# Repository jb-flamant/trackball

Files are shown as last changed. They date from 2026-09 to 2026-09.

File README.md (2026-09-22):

# Trackball 34 mm — PMW3610 / RP2040-Zero

Coque de trackball DIY paramétrique en OpenSCAD, dessinée pour une bille de
Ø34 mm, un capteur optique **PMW3610** et un microcontrôleur **RP2040-Zero**.

Le modèle est dérivé de [**Trackball 1.5** de jfedor (Printables #131450)](https://www.printables.com/model/131450-trackball-15),
conçu à l'origine pour une boule de billard Ø38 mm. Les cotes du support de
bille, de l'embase et du passage de câble ont été relevées sur les surfaces
analytiques du fichier source `Trackball15.step` (lecture cadquery/OCP, valeurs
exactes), puis transposées à la bille Ø34.

## Caractéristiques

- **Bille Ø34 mm** portée par 3 billes de roulement Ø2,5 (tripode à 60° du
  nadir, azimuts 30/150/270°), reprises telles quelles de l'original.
- **Retenue clipsable** (ajout par rapport à l'original) : trois languettes
  souples terminées par une lèvre arrondie empêchent la bille de sortir par le
  haut. Ouverture Ø33,46, clipsage/déclipsage par interférence, à la manière de
  la bague d'une Kensington Orbit.
- **Embase carrée** 52 × 55,75 mm, angles R8, montage par 4 vis M3 fraisées par
  dessous, taraudées dans la coque haute.
- **Passage de câble** en U dans la paroi avant, refermé par la coque haute
  (repris de l'original).
- Logements dédiés pour le breakout **PMW3610** (en long, optique centrée sous
  la bille) et le **RP2040-Zero** (en travers, derrière).

## Fichiers

| Fichier | Description |
| --- | --- |
| `trackball.scad` | Modèle paramétrique (OpenSCAD 2021.01). |
| `index.html` | Page de documentation (cotes, coupes, vues, reste à faire). |
| `*.png` | Rendus référencés par la page HTML. |

## Utilisation

Ouvrir `trackball.scad` dans [OpenSCAD](https://openscad.org/) (≥ 2021.01). La
variable `RENDER` sélectionne la pièce ou la vue à générer :

| Valeur | Rendu |
| --- | --- |
| `assembly` | Assemblage complet (défaut). |
| `top` | Coque haute (support de bille + retenue). |
| `bottom` | Bac électronique. |
| `section_h` | Coupe horizontale au plan des billes de roulement. |
| `section_v` | Coupe verticale (X = 0). |

Les principaux paramètres (diamètre de bille, jeux, interférence des lèvres,
dimensions des cartes, vis) sont regroupés en tête de fichier et documentés
inline. Exporter chaque pièce en STL depuis OpenSCAD pour l'impression.

Matière conseillée : **PETG** (le PLA est à la limite pour la flexion des
languettes de retenue).

## Reste à faire

Voir la section « Reste à faire avant impression définitive » de `index.html` :
support de lentille LM18-LSI/PMW3610 non modélisé, hypothèses sur la hauteur du
RP2040-Zero et le passage USB-C, coupon d'essai plaque + 3 poteaux recommandé
avant l'impression complète.

## Références

- [Trackball 1.5 — jfedor (Printables #131450)](https://www.printables.com/model/131450-trackball-15) — modèle de base.
- [siderakb/pmw3610-pcb](https://github.com/siderakb/pmw3610-pcb) — breakout PMW3610.
- [OpenSCAD](https://openscad.org/) — logiciel de CAO paramétrique.

## Crédits & licence

Travail dérivé de Trackball 1.5 (jfedor). Vérifier les conditions de licence du
modèle d'origine sur sa page Printables avant toute redistribution.

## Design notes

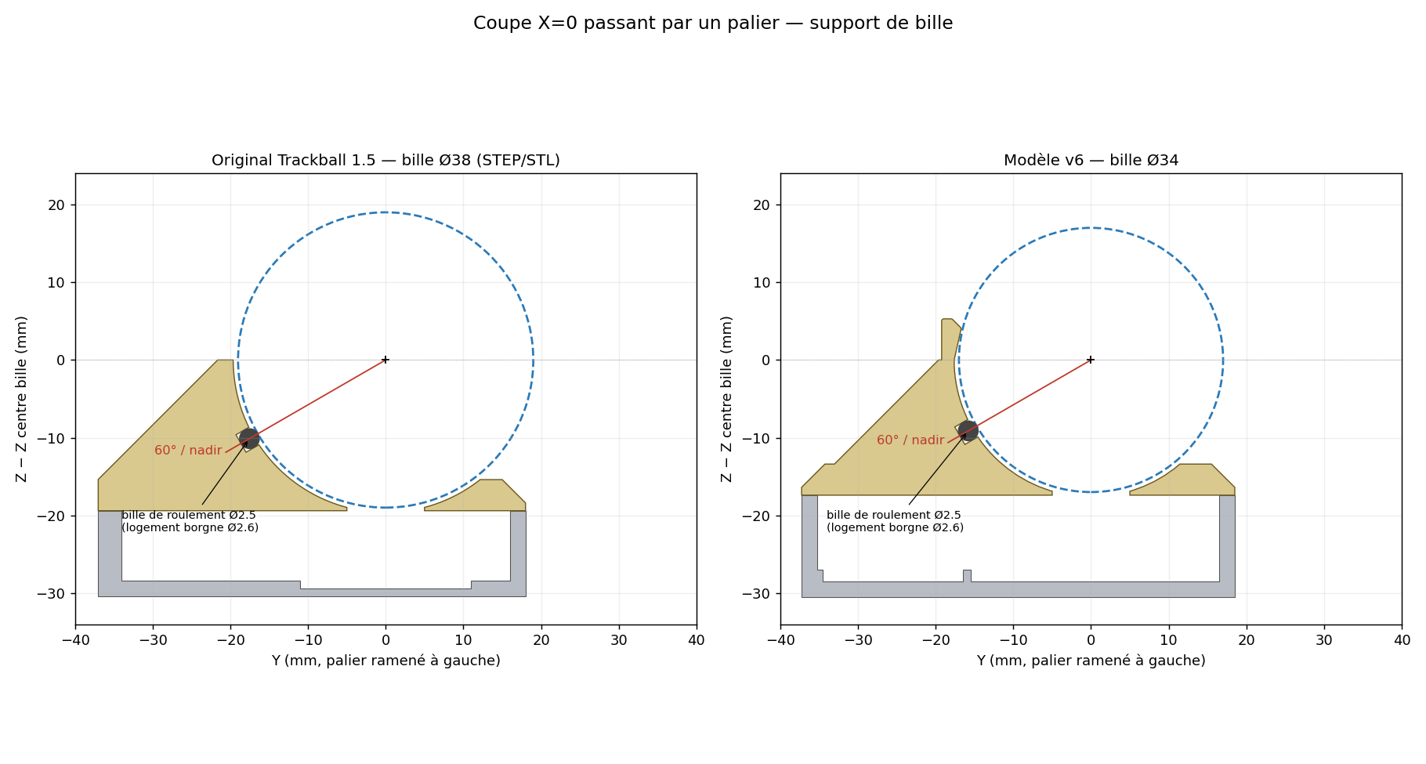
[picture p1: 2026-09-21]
comparaison_support_bille.png

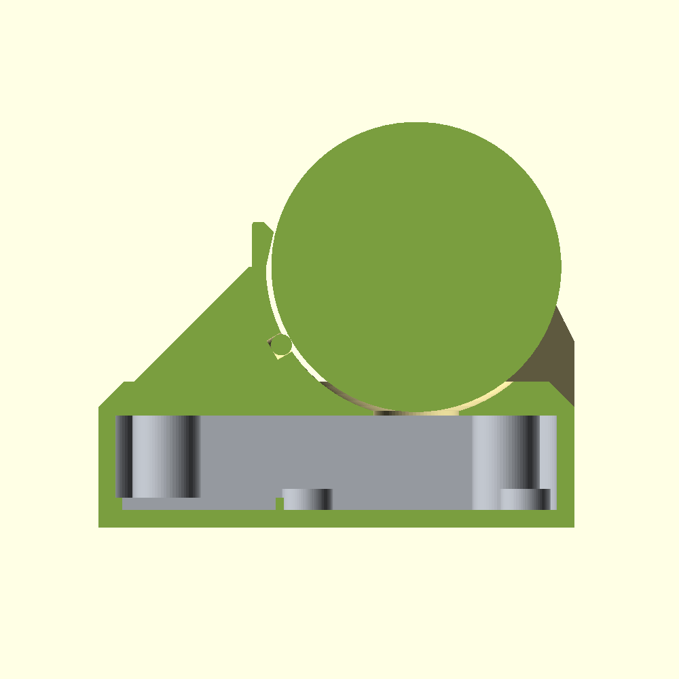
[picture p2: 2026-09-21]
section_verticale.png

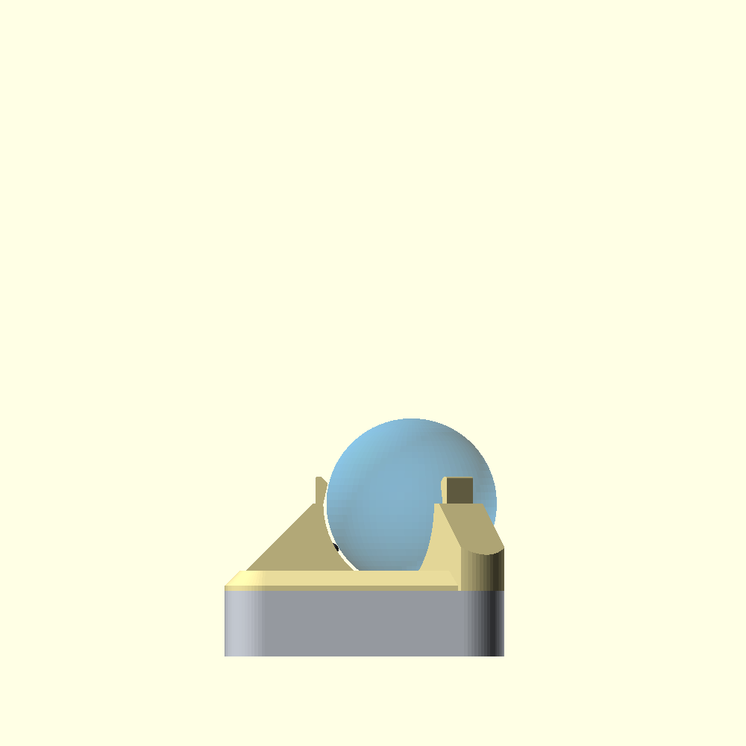
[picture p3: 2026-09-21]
view_droite.png

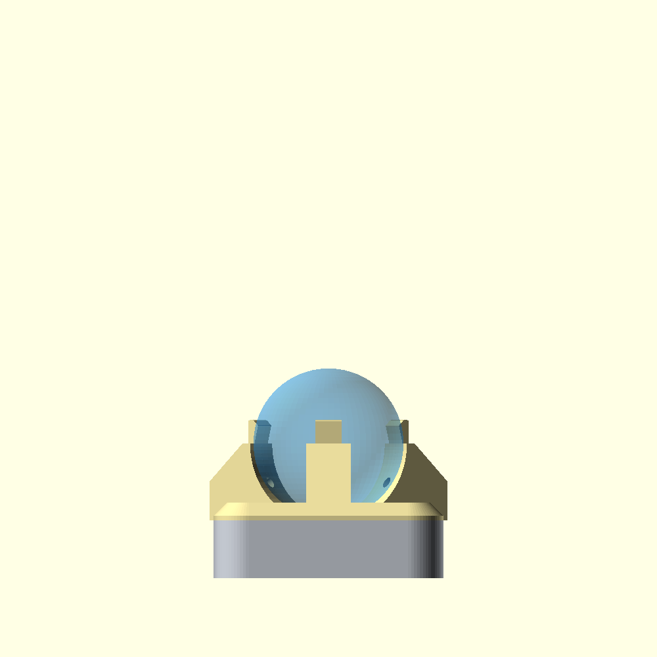
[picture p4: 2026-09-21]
view_dos.png

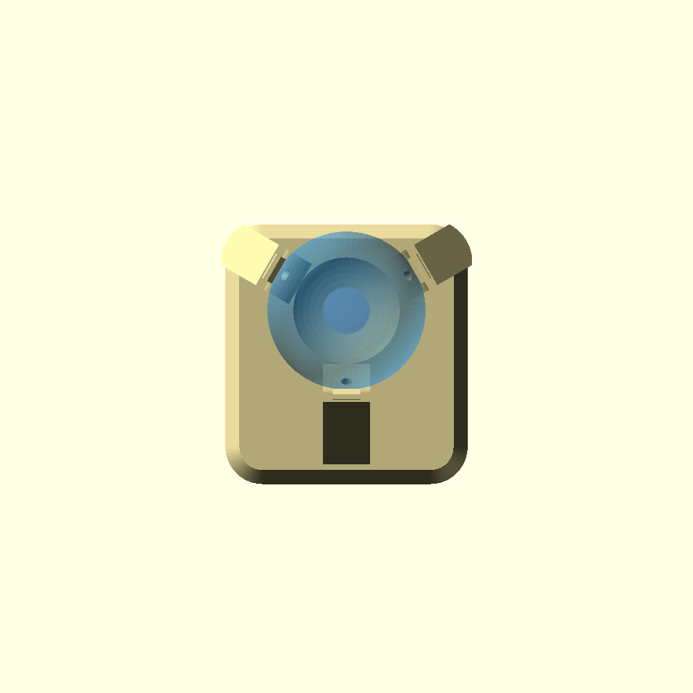
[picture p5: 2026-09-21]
view_haut.png

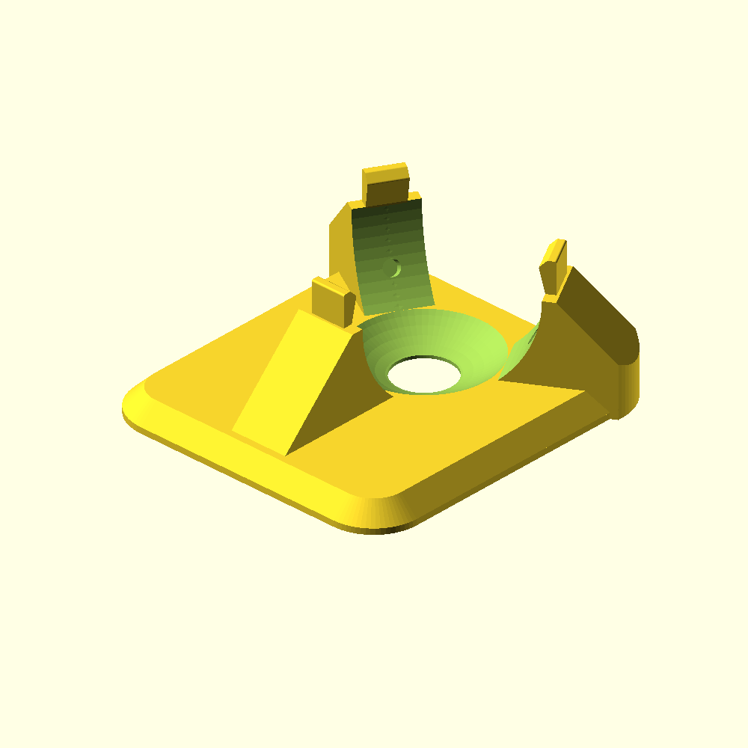
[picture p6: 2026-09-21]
iso_top_only.png

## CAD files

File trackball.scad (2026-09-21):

// =============================================================================
// Trackball DIY paramétrique — bille 34mm / PMW3610 / RP2040-Zero      (v7)
// =============================================================================
// Dérivé de "Trackball 1.5" (jfedor, Printables #131450), dessiné pour une boule de
// billard 38mm. Cotes lues sur les surfaces analytiques de Trackball15.step
// (cadquery/OCP), voir doc projet claude/mesures-step-trackball15.md.
//
// SUPPORT DE BILLE (v4, repris tel quel de l'original, transposé à 34mm) :
//   calotte R+0.625, ouverture Ø10, plaque 4mm, plan de joint 0.4mm sous le pôle sud,
//   3 billes de roulement Ø2.5 dans logements borgnes Ø2.6 à 60° du nadir, azimuts
//   30/150/270, murs-poteaux 10mm montant jusqu'à l'équateur.
// EMBASE CARRÉE (v5, reprise de l'original) :
//   corps rectangulaire largeur 52 (x ±26), angles R8, parois et fond 2mm, bord de
//   plaque vertical 1mm puis chanfrein 45° sur 3mm ; les poteaux dépassent le corps de
//   1mm (angles avant R9, nervure arrière) ; 4 vis M3 aux centres d'angle, montées par
//   dessous (fraisage dans le fond), taraudées dans la coque haute (avant trou pilote
//   Ø2.8 dans le poteau, arrière dans la plaque), comme sur l'original.
//   Profondeur : original y -36 → +18 autour de l'axe bille ; ici ajustée pour loger
//   le PMW3610 (en long, centré sous la bille) et le RP2040-Zero (en travers, derrière).
// RETENUE CLIPSABLE (v6, ajout, pas sur l'original) :
//   chaque poteau est prolongé au-dessus de l'équateur par une languette souple (6mm de
//   large, 1.6mm d'épaisseur) portant une lèvre arrondie tournée vers l'intérieur.
//   Ouverture entre les lèvres < Ø bille de 2×lip_interf : la bille se clipse en force
//   (rampe d'entrée à 45°) et se retire en tirant (face inférieure en pente), comme la
//   bague de la Kensington Orbit. Au repos, jeu lèvre/bille lip_clear ; la bille peut
//   se soulever d'environ 1mm avant de buter. Effort estimé ≈20N au total (PETG).
// PASSAGE DE CÂBLE (v7, repris de l'original) : encoche en U dans la paroi avant du bac
//   (côté bille), centrée x = -12, largeur 5, fond R2.5 à 5.5mm sous le plan de joint ;
//   la coque haute referme l'encoche.
// Provenance de chaque cote : STEP (mesuré sur l'original), DATASHEET, CHOIX.
// =============================================================================

/* [Bille] */
ball_d          = 34;      // spec projet (38 à l'origine)
ball_r          = ball_d/2;

/* [Support de bille] — STEP Trackball 1.5, valeurs indépendantes du diamètre */
cup_clearance   = 0.625;   // STEP : jeu radial calotte/poteaux ↔ bille
brg_ball_d      = 2.5;     // STEP : billes de roulement Ø2.5 (céramique/acier)
brg_hole_d      = 2.6;     // STEP : logement Ø2.6
brg_polar       = 60;      // STEP : angle depuis le nadir (60.0° exact)
brg_az          = [30, 150, 270]; // STEP : 30/150 vers les angles avant, 270 vers l'arrière
post_w          = 10;      // STEP : largeur des murs-poteaux
post_top_flat   = 2;       // STEP : épaisseur radiale du sommet plat
post_overhang   = 1;       // STEP : dépassement des poteaux hors du corps (R9 vs R8)
plate_t         = 4;       // STEP : épaisseur plaque haute (Z 7→11)
plate_edge_v    = 1;       // STEP : bord vertical de la plaque (Z 7→8)
plate_chamfer   = 3;       // STEP : chanfrein 45° (Z 8→11)
split_below_pole= 0.4;     // STEP : plan de joint sous le pôle sud de la bille
aperture_d      = 10;      // STEP : ouverture optique au fond de la calotte

/* [Retenue clipsable] — CHOIX (v6) */
lip_interf      = 0.3;     // interférence radiale par lèvre (ouverture = Ø bille − 2×lip_interf)
lip_clear       = 0.2;     // jeu lèvre ↔ bille au repos
lip_finger_t    = 1.6;     // épaisseur radiale de la languette (flexion)
lip_finger_w    = 6;       // largeur de la languette (centrée sur le poteau)
lip_lead        = 1.2;     // hauteur de la rampe d'entrée à 45° au-dessus de la lèvre
lip_round       = 0.3;     // arrondi du nez de lèvre

/* [Embase carrée] */
base_w          = 52;      // STEP : x ±26
front_min       = 18;      // STEP : bord avant à 18mm de l'axe bille (bille en porte-à-faux)
corner_r        = 8;       // STEP : rayon des angles
wall            = 2.0;     // STEP : parois du bac
floor_t         = 2.0;     // STEP : fond du bac
pillar_r        = 4;       // CHOIX : piliers de vis dans les angles du bac
elec_gap        = 0.75;    // CHOIX : jeu autour des cartes

/* [Passage de câble] — STEP : encoche en U dans la paroi avant du bac */
cable_x         = -12;     // STEP : centre de l'encoche
cable_w         = 5;       // STEP : largeur (fond R2.5)
cable_depth     = 5.5;     // STEP : profondeur sous le plan de joint

/* [Vis] — M3 fraisée par dessous, taraudée dans la coque haute (comme l'original) */
screw_clear_d   = 3.4;
screw_head_d    = 6.5;     // fraisage 90°
screw_pilot_d   = 2.8;     // STEP : trou pilote Ø2.8
pilot_depth_front = 8;     // CHOIX : dans le poteau avant
pilot_depth_back  = 3.5;   // STEP : 3mm dans la plaque d'origine

/* [PMW3610 breakout] — plan coté fabricant */
pmw_hole_dx     = 17.5;
pmw_hole_dy     = 25.5;
pmw_hole_d      = 3.2;
pmw_thickness   = 1.6;

/* [Empilement optique PMW3610] — DATASHEET PMW3610DM-SUDU */
lens_gap        = 2.4;     // Table 2 : lentille -> surface, 2.2/2.4/2.6
pcb_top_to_ball = 7.40;    // Fig.4 : "Top of PCB to Surface" (montage de référence)

/* [RP2040-Zero] — fiche vendeur */
rp_w            = 18.0;
rp_h            = 24.0;
rp_thickness    = 1.6;     // CHOIX
rp_h_components = 3.5;     // CHOIX (hypothèse) : composants + USB-C

/* [Supports cartes] */
standoff_h      = 2.5;     // CHOIX

/* [Rendu] */
RENDER    = "assembly";    // assembly | top | bottom | section_h | section_v
SHOW_BALL = true;          // bille + billes de roulement de référence (hors STL)
$fn = 72;

// =============================================================================
// Repères verticaux (Z=0 = dessous du bac)
// =============================================================================
pcb_top_z     = floor_t + standoff_h + pmw_thickness;
ball_south_z  = pcb_top_z + pcb_top_to_ball;       // DATASHEET
ball_center_z = ball_south_z + ball_r;
split_z       = ball_south_z - split_below_pole;   // STEP (principe)
plate_top_z   = split_z + plate_t;
R_cup         = ball_r + cup_clearance;
brg_r         = ball_r + brg_ball_d/2;             // centre bille de roulement
brg_bottom_r  = ball_r + brg_ball_d;               // fond du logement
rp_top_z      = floor_t + rp_thickness + rp_h_components;
lip_r_tip     = ball_r - lip_interf;                              // rayon horizontal du nez
lip_h         = sqrt(ball_r*ball_r - pow(lip_r_tip - lip_clear, 2)); // hauteur du nez / équateur

// =============================================================================
// Embase : rectangle à angles R8 ; profondeur calculée pour les deux cartes
// =============================================================================
pmw_len  = 31.5;  pmw_wid = 23.5;                  // plan coté (en long selon Y)
front_y  = max(front_min, pmw_len/2 + elec_gap + wall);
rp_cy    = -(pmw_len/2 + elec_gap + rp_w/2);       // RP2040 en travers, derrière le PMW3610
back_y   = -(pmw_len/2 + elec_gap + rp_w + elec_gap + wall);
corner_c = [[ base_w/2-corner_r, front_y-corner_r], [-(base_w/2-corner_r), front_y-corner_r],
            [ base_w/2-corner_r, back_y+corner_r],  [-(base_w/2-corner_r), back_y+corner_r]];
screw_pos = corner_c;

echo(str("embase ", base_w, " x ", front_y-back_y, "  (y ", back_y, " -> ", front_y,
         ")  split_z=", split_z, " plate_top_z=", plate_top_z, " ball_center_z=", ball_center_z));
assert(abs(cable_x) + cable_w/2 <= base_w/2 - corner_r, "Encoche de câble dans l'arrondi d'angle");
assert(split_z >= rp_top_z + 0.5, "Plan de joint trop bas pour le RP2040-Zero");
assert(base_w/2 - corner_r - pillar_r >= pmw_wid/2 + 0.5, "Piliers avant en collision avec le PMW3610");
assert(base_w/2 - corner_r - pillar_r >= rp_h/2 + 1, "Piliers arrière en collision avec le RP2040");

module footprint_2d() {
    hull() for (c = corner_c) translate(c) circle(r=corner_r);
}

// direction radiale (unitaire) du palier i, depuis le centre bille
function brg_dir(i) = [sin(brg_polar)*cos(brg_az[i]), sin(brg_polar)*sin(brg_az[i]), -cos(brg_polar)];
function brg_center(i) = [0,0,ball_center_z] + brg_r*brg_dir(i);

// =============================================================================
// BAC ÉLECTRONIQUE (bas)
// =============================================================================
// encoche en U traversant la paroi avant, ouverte vers le haut (fermée par la coque haute)
module cable_notch() {
    zc_cable = split_z - cable_depth + cable_w/2;
    translate([cable_x, front_y - wall - 1, 0]) {
        translate([0,0,zc_cable]) rotate([-90,0,0]) cylinder(d=cable_w, h=wall+2, $fn=48);
        translate([-cable_w/2, 0, zc_cable]) cube([cable_w, wall+2, cable_depth]);
    }
}
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

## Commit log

2026-09-21 Add parametric trackball OpenSCAD model
    Modèle paramétrique v7 (bille 34mm, PMW3610, RP2040-Zero) dérivé de
    Trackball 1.5 : support de bille, embase carrée, retenue clipsable et
    passage de câble.
    Claude-Session: https://claude.ai/code/session_01X6jfmfG5x5RUXvk1ZSSYZc
    [trackball.scad]
2026-09-21 Add project documentation page
    Page HTML de documentation du modèle (cotes, coupes, vues, reste à
    faire). Les images de rendu ne sont pas incluses.
    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
2026-10-15 Firmware Zephyr (souris HID USB) + réorganisation hardware/software (#1)
    * Split repo into hardware/ and software/ folders
    Déplace le modèle 3D (trackball.scad, index.html, rendus PNG) dans
    hardware/ et crée software/ pour le futur firmware Zephyr/RP2040.
    Met à jour les chemins dans le README.
    * Scaffold Zephyr firmware for RP2040-Zero + PMW3610
    Squelette d'application Zephyr reliant le capteur PMW3610 au RP2040-Zero :
    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
2026-10-15 Add I2C target output (trackball as I2C module)
    En plus de la souris HID USB, le RP2040 s'enregistre comme peripherique
    I2C target (CONFIG_I2C_TARGET, driver DesignWare) sur i2c0 (GP28=SDA,
    GP29=SCL), pour servir de module lu par un controleur hote.
    - overlay : pinctrl i2c0 (GP28/GP29) + noeud i2c0 @100kHz
    - prj.conf : CONFIG_I2C, CONFIG_I2C_TARGET
    - src/i2c_target.c/.h : enregistrement target + carte de registres
    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
2026-10-19 Document power ORing (USB or I2C host 3V3)
    Ajoute une section « Alimentation : USB ou hote I2C » : le trackball peut
    etre alimente par son USB-C ou par le 3V3 de l'hote (module pur). Le
    RP2040-Zero n'ayant pas de 3V3_EN, une diode Schottky d'OR-ing sur la ligne
    3V3 permet l'un ou l'autre sans conflit. Precise aussi que seuls SDA/SCL/GND
    relient les deux cartes (masse commune, pull-ups cote hote) et liste des
    references de diodes (PMEG2010ER, 1N5817...) + option ideal-diode.
    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
